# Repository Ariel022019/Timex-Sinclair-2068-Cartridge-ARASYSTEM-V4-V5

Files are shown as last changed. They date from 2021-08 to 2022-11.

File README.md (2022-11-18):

## :small_blue_diamond: Timex-Sinclair-2068-Cartridge-ARASYSTEM-V4-V5
This is a cartridge for Timex Sinclair 2068, to work with EPROMs 28C64, 27C128, 27C256, 27C512, EEPROMs 28C54, 28C256 and Static RAM 66256, 84256 and another with the same characteristics.  Using jumpers or mini switches, this PCB can be configured to get different settings.
With its unique design, there is no need to configure bridges to select fragments. The chunks can be configured by software.

### :small_blue_diamond: Jumpers configutation for each kind of EPROM /EEPROM

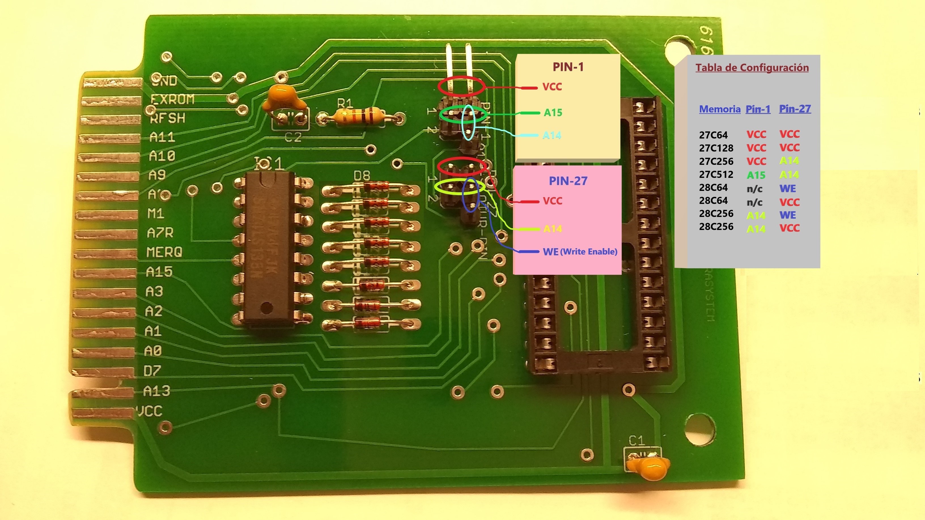
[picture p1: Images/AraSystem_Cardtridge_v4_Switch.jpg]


### :small_blue_diamond: Place right way to the socket the EPROM / EEPROM 

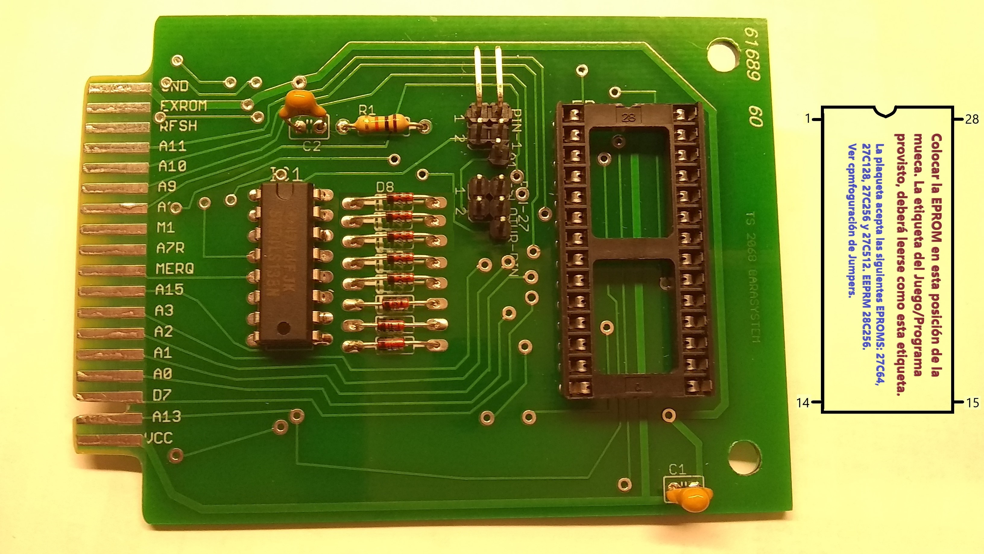
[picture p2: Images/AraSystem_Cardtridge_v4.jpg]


#### 🔸 Watch the creation of the first cartridge on video 
[Youtube Video Link](https://www.youtube.com/watch?v=S2ucEzxKyNs)

### 🔹 Cartridges With Mini Switches.
These mini switches allows to divide the EPROM memory into two or four parts, depending on the size of the EPROM (32k or 64K).

######  ▪️ ▪️ EPROM 27C256 divided into two 16K sizes


[See video example on Youtube](https://www.youtube.com/watch?v=SSa5LG2SbeI)

######  ▪️ ▪️ EPROM 27C512 divided into four 16K sizes


[See video example on Youtube](https://www.youtube.com/watch?v=w1bCyKRASG4)

######  ▪️ ▪️ Combining various configurations with switches and jumpers
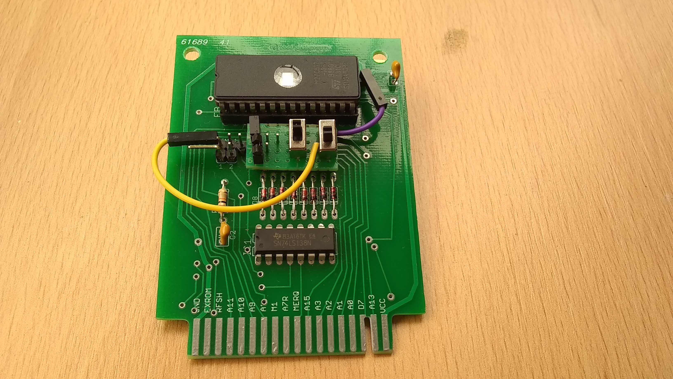
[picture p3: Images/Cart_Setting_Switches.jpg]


### 🔹 Timex Sinclair 2068 Cartridge With 32K Static RAM 
This cartridge is used to expand 32K of RAM and store your own programs or data, which are stored in memory through a 3 Volt battery. Both the cartridge board and the battery holder board have their protection diodes, so as not to interfere with the voltages between them.
Commercial programs that start in AROS mode can also be stored. (Only one game at a time, eg Flight Simulator, Androids, Crazy Bugs, Casino 1 and others).
this system is that they can generate / experiment cartridges, without the need for burners and / or ERPOM erasers.

######  ▪️ ▪️ Battery connection.


######  ▪️ ▪️ Static RAM located in the socket.


######  ▪️ ▪️ Inserted inside the Dock Bank.
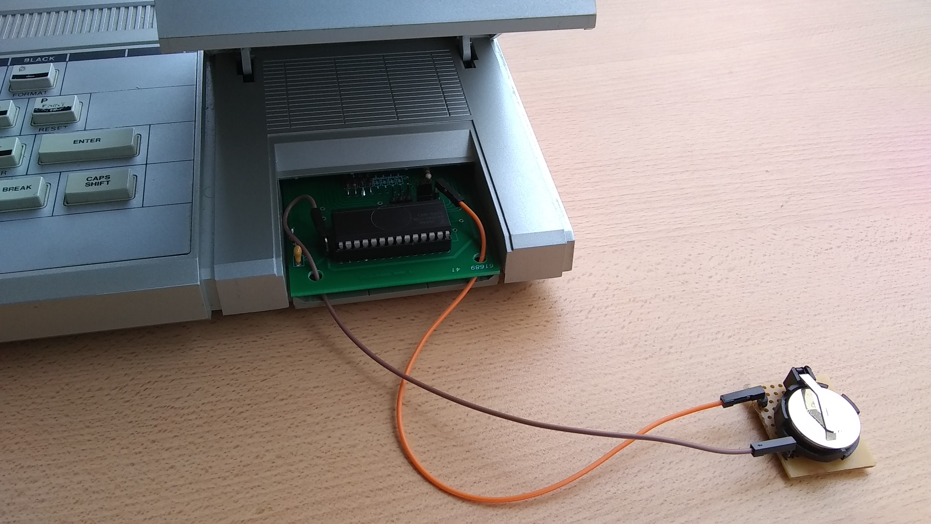
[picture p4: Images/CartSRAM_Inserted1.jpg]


[Demo on Youtube](https://www.youtube.com/watch?v=_XW6AfT9foQ)

## 🔸 License.

######  UNDER LICENSE: CC BY NC ND 4.0
- You may not use the material for commercial purposes.

<a rel="license" href="http://creativecommons.org/licenses/by-nc-nd/4.0/">Attribution-NonCommercial-NoDerivatives 4.0 International</a><br />

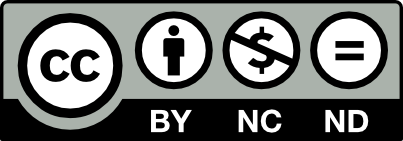
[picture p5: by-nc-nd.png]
Licencia de Creative Commons


#### 🔹 You can get these cartridges or more information:

Contact to: ariel.ranieri.sistemas@gmail.com

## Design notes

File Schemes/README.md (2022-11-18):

## 🔹 Design for every need.

This cartridge can be setting according to the needs of the end user

### 🔹 Cartridge scheme to replace jumpers using a switch and a jumper.

###### ◾ EPROM 27C256 divided into two equal parts 16K in size
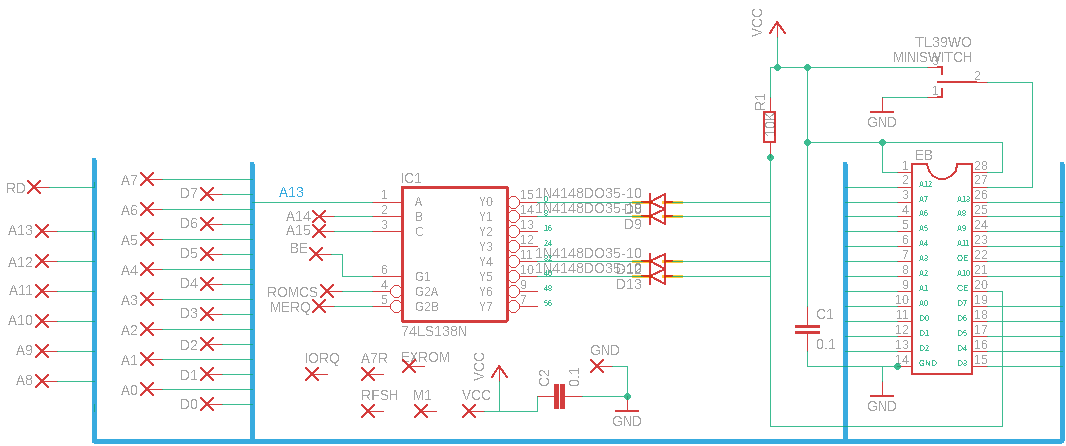
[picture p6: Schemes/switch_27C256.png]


###### ◾ EPROM 27C512 divided into two equal parts 32K in size
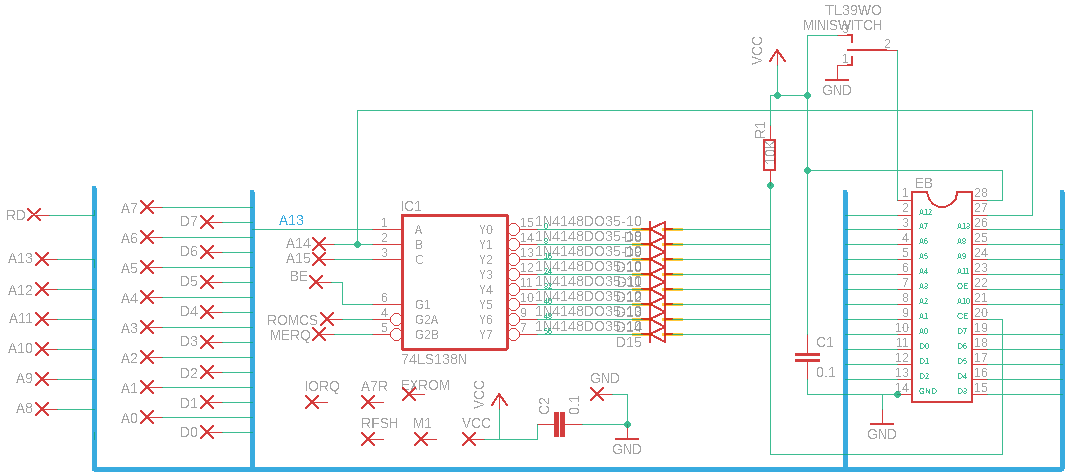
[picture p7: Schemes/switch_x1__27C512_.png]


### 🔹 Cartridge scheme to replace jumpers using two switch.

###### ◾ EPROM 27C512 divided into four equal parts 16K in size
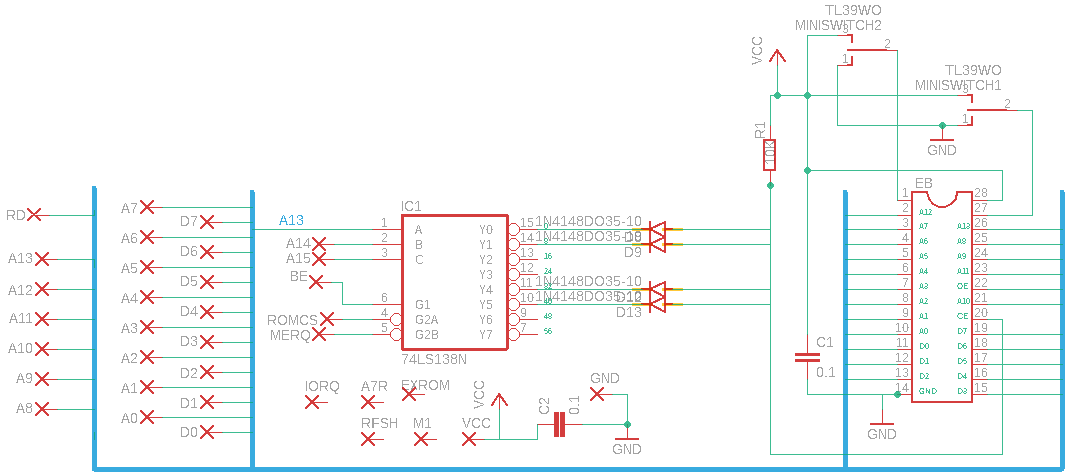
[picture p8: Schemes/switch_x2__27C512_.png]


### 🔸 Cartridge scheme to use static ram and battery.

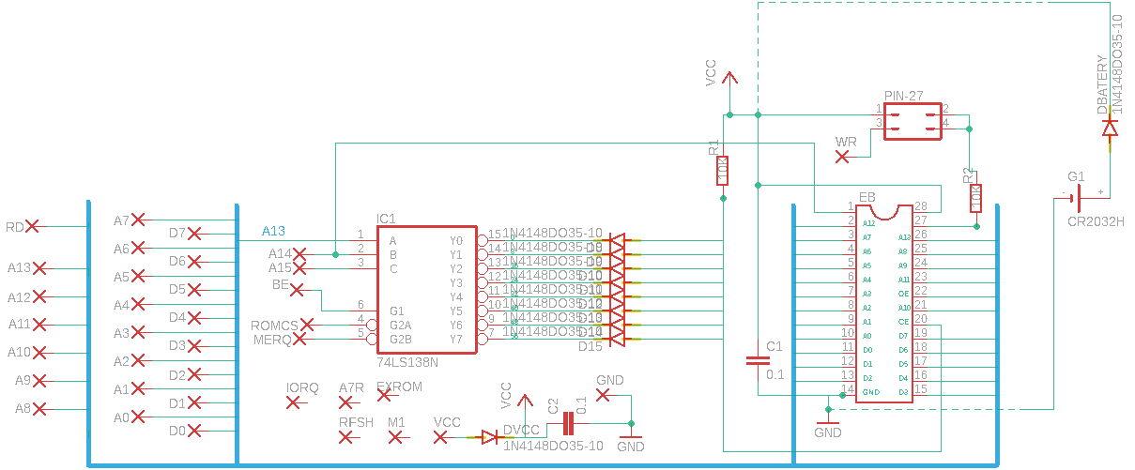
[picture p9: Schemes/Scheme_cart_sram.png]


### 🔸 Cartridge PCB Layer TOP.

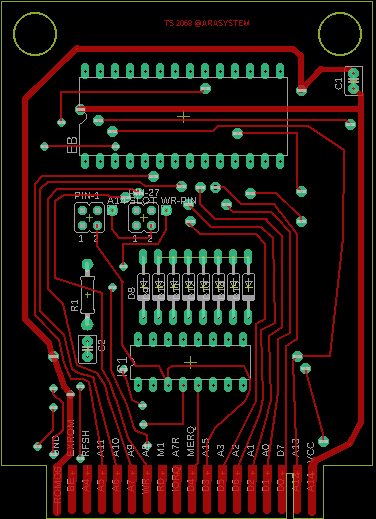
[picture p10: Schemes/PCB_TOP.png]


### 🔹 Cartridge PCB Layer Bottom.

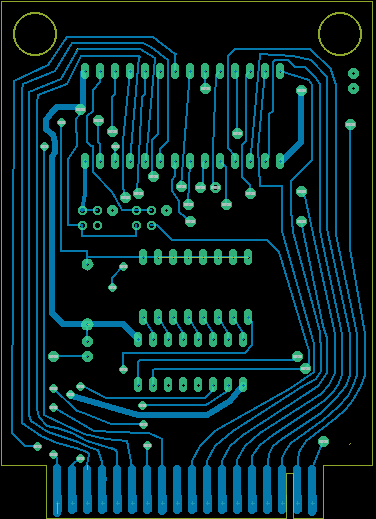
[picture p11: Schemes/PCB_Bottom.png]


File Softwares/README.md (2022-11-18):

## 🔹 Software Pack Built for Timex Sinclair 2068 Cartridges.

I have made several sets of programs for these cartridges. All files have the .Dck extension. That is means you can run this files on some Emulator like FUSE or others. Remember to skip or delete the first nine bytes when you want to write the binary file to some EPROM.
In this section I'll focus on the others games (most of the Spectrum games) and skip the seven classic games made for cartridges on the TS2068.

You will see that in all projects, I am using the emulator FUSE for get Snap Shot files, and then I am using the "SnapToTap R2.3 (PC/Windows), by Arda Erdikmen" for to convert from Snap Shot files to TAP format  from 
this URL: [World Of Spectrum Utilities](https://worldofspectrum.net/utilities/)

The binary file can be created to start or boot in LORS mode [Cartridge Loader Maker:](https://www.retrocomputacion.com/forum/hardware_s/108010/eproms-para-las-plaquetas-timex-sinclair-2068-command-cartridge-v2/&p=7), or in AROS mode  [Cartridge Maker AROS V2:](https://www.retrocomputacion.com/forum/hardware_s/108010/eproms-para-las-plaquetas-timex-sinclair-2068-command-cartridge-v2/&p=8)
Both web pages (they are in Spanish) explain how to do it.

### 🔹 Start in Mode LROS EEPROM 28C256 or EPROM 27C256.

The steps for make cartridges booting in LORS mode are:
1) From the FUSE Emulator in TS2068 mode, Load a program TZX or TAP file and then Create a Snap Shot file and save it on disk.
2) Convert Snap Shot file to .TAP .
3) Again From the FUSE program, load the "Cartridge Loader Maker" software and get the binary file.
4) Burn the binary file on the eprom.

### 🔹 Start in Mode AROS EEPROM 28C256 or EPROM 27C256.

The steps for make cartridges booting in AORS mode are:
1) From the FUSE Emulator in TS2068 mode, load a program TZX or TAP file and then Create a Snap Shot file and save it on disk.
2) Convert Snap Shot file to .TAP .
3) Again From the FUSE program, load the "Cartridge Maker AROS V2" software and get the binary file.
4) Burn the binary file on the eprom.

### 🔹 Start in Mode AROS With Menu from EPROM 27C512.
Make cartridges with two Games. The steps to do are:
Instructions for creating a Basic Menu To select two SnapShot programs. (Use the FUSE Emulator Program in TS2068 mode).

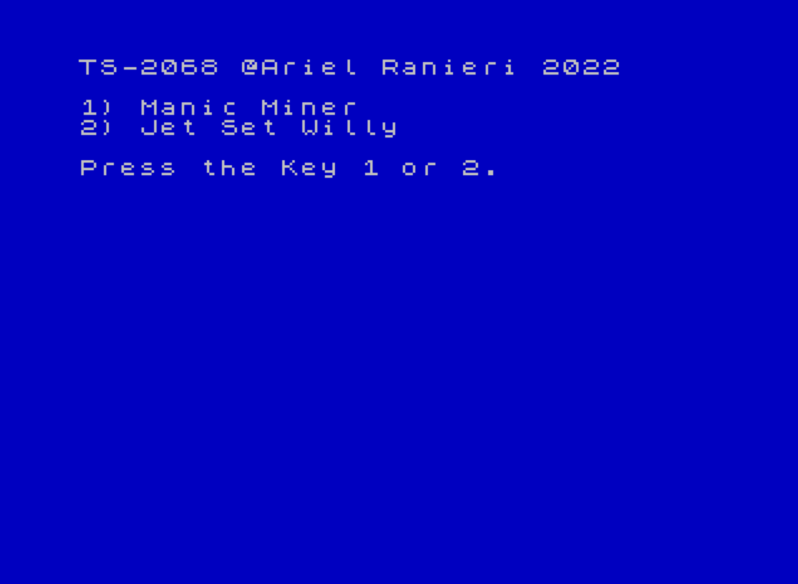
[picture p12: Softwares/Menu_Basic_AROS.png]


1) Create a snapshot for cartridge with LROS boot.
2) Create a Snap Shot for Cartridge with AROS boot.
3) Eraase the boot LROS mode(put 0 from the second byte to fourth byte in the file) and save it.
4) Change the boot AROS mode to AROS Basic (put 1 on the first byte in the file) and save it.
5) From the FUSE Emulator in TS2068 mode, load the Program Menu_Basic_AROS.tzx file, then edit line 5 and write the names of the programs. The first program "1)",    executes the snapshot prepared to boot type LROS. The second program "2)", executes the snapshot, ready to start type AROS.
6) Save from the FUSE in binary format with file name menu_basic_LORS_AROS.bin, as Start = 26710 , Length = 320.
7)  Load the binary file (created in the item 2) from memory address 32768 an then load the other binary file menu_snap_LROS_AROS.bin from the FUSE, with the Start    parameter = 32776, and Length the one indicated by the size of the binary file (320 bytes, it must not exceed this size as described above).
8) Load the binary file headerAros.bin from the FUSE, with the parameter Start = 33096, and Length the one indicated by the size of the binary file (168 , respect this size).
9) Save from the FUSE the program in binary format as Start = 32768 and length = 32768.
10) Concatenate with the DOS COPY command, the two binary files to burn them on 27C512 EPROM (Using for example the Xgpro TL866II PLUS program). 
    copy /b CARTRIDGE_SMAP_LROS.bin+CARTRIDGE_SMAP_AROS.bin MI_CARTRIDGE_FINAL.bin .
11) If you want to test it in the Fuse emulator, we add the 9 Bytes header (0-2-2- 2-2-2-2-2-2)
    copy /b Header_DOCK.bin+MI_CARTRIDGE_FINAL.bin Cartridge.dck 
    
#### 🔸 Videos Youtube
[Cartridge: Manic Minier and Jet Set Willy](https://www.youtube.com/watch?v=gIqrhjyPwj8)

[Cartridge: ROM ZX Spectrum and Poe Position](https://www.youtube.com/watch?v=1JByrzgxnWw)

### 🔹 Built to lung and using too much the wrist.
This is the hardest way to build cartridges that boot the programs from any Dock Bank memory address.
The 7Games9K.DCK (7 Games 9K bytes) and 8Games8K.DCK (8 Games 8K bytes) files are more complicated to build. It is necessary to make an installer for each of the games and place them in the best place in the eprom (27C512). And play with the eight 8Kbyte chunks, the Stack Point and other environments.

#### 🔸 Videos Youtube
[Cartridge: 7 Games of 9Kbytes](https://www.youtube.com/watch?v=phbGwPkzN14)

[Cartridge 8 Games of 8Kbytes](https://www.youtube.com/watch?v=hWecyYZo_lU)

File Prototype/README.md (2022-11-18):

## 🔹  Cartridge-Prototype-ARASYSTEM-V4
Theses were the first steps for build the unique cartridge prototye. 

### :small_blue_diamond: PCB - Scheme

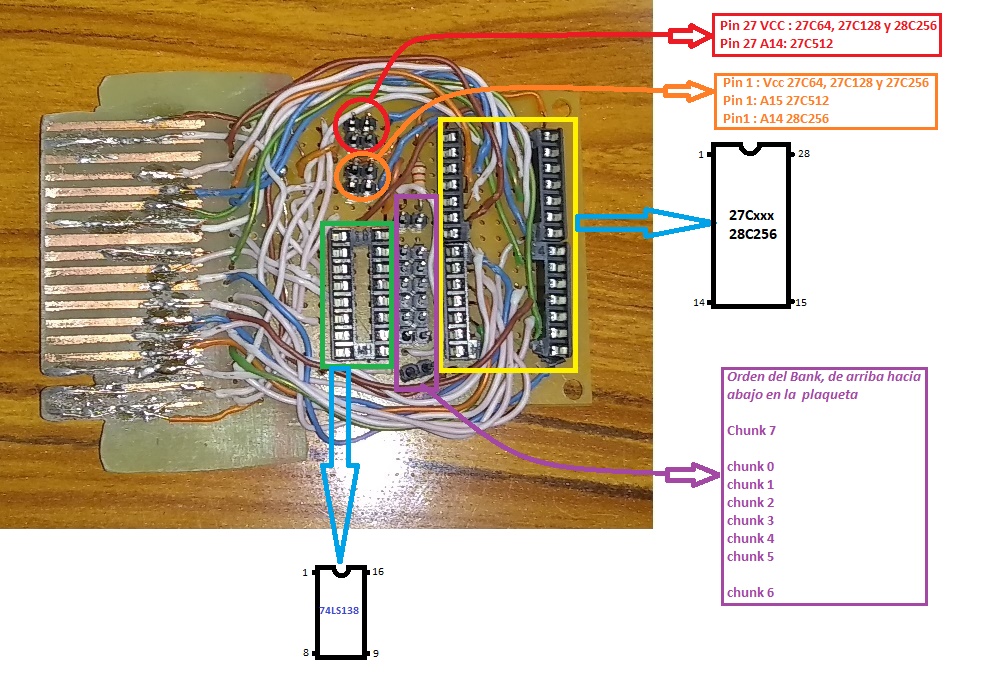
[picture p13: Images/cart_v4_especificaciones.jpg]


### :small_blue_diamond: PCB Prototype on Dock Bank Slot

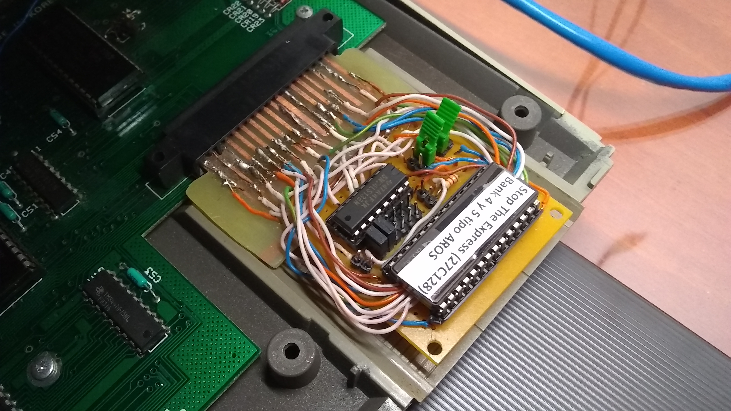
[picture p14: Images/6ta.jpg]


### 🔹 Final design, adding an external protobard.

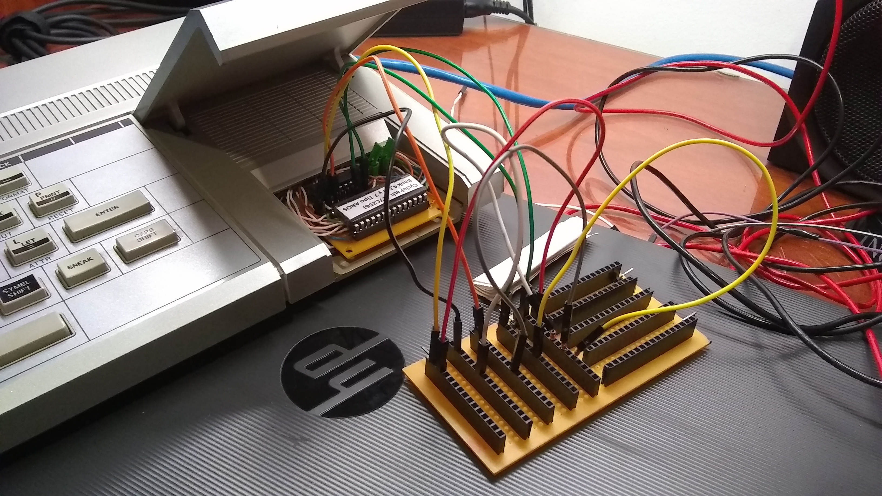
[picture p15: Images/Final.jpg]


### 🔹 PCB Ready!.

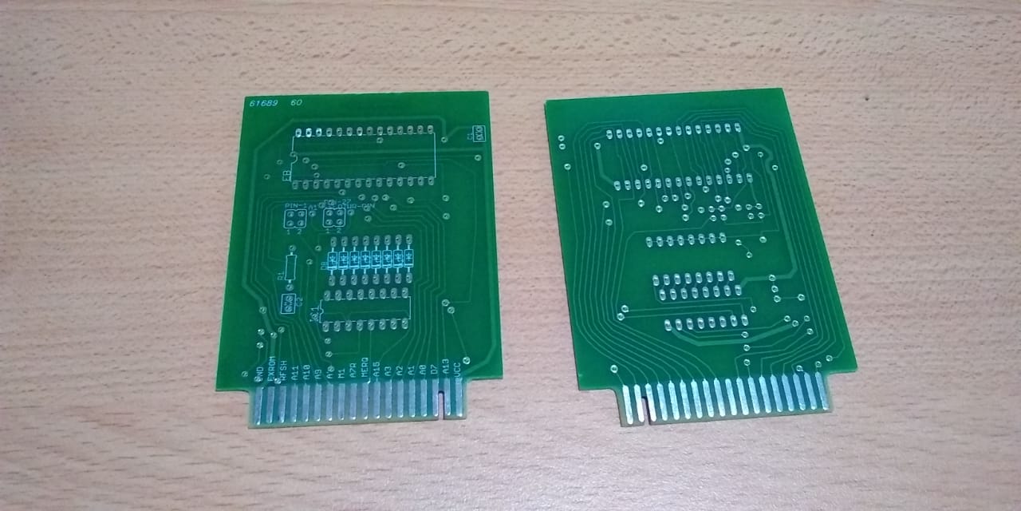
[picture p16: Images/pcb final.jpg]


### 🔹 New PCB with components and located on Dock Bank.

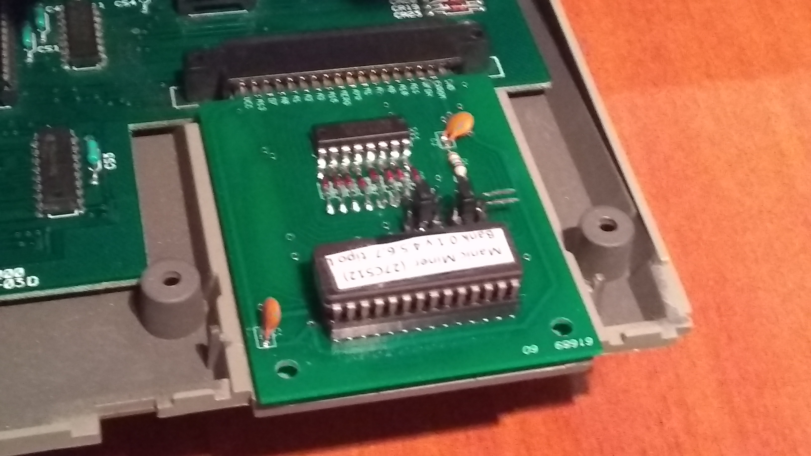
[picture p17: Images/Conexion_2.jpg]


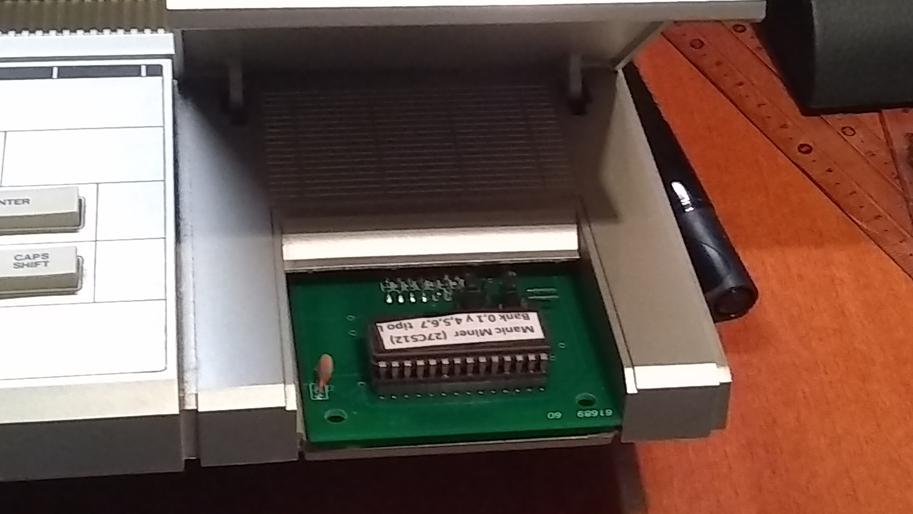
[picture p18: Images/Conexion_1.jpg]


### 🔹 The Laboratory.

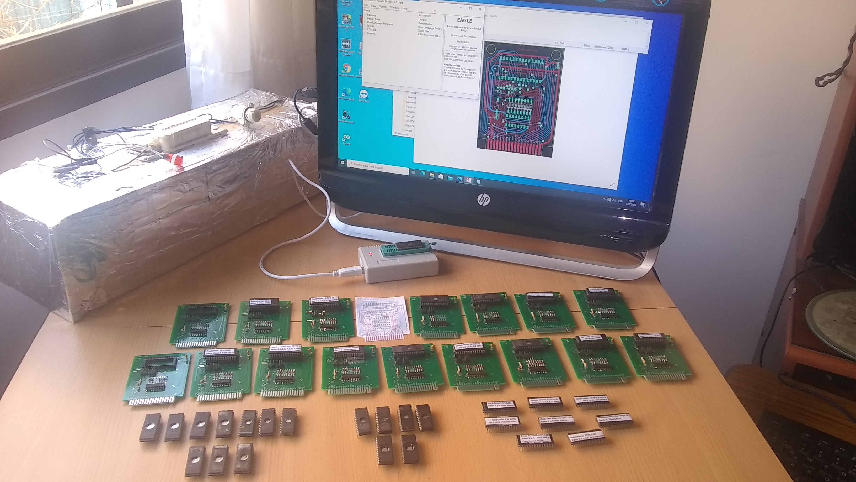
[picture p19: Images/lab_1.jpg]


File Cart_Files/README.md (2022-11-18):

## 🔹 How to use the WriteCart program in TS2068 to create your own cartridges.

[Link How To on Youtube](https://www.youtube.com/watch?v=_XW6AfT9foQ)

### 🔸 Step 1. Load the file WriteCart.tzx in TS2068.

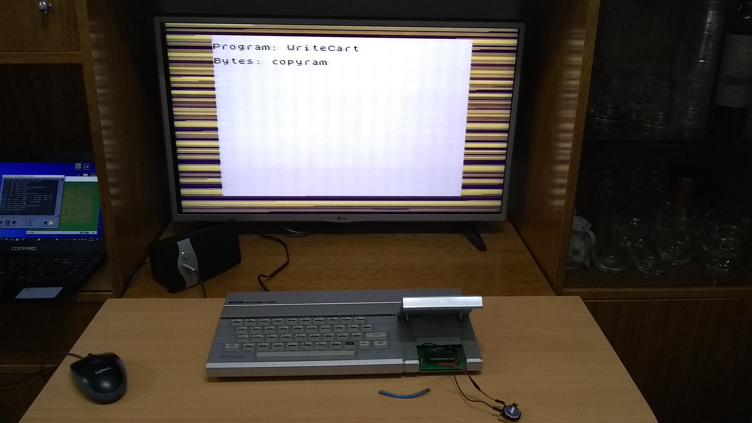
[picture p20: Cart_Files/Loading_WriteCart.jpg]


### 🔸 Step 2. Choice the option 1)

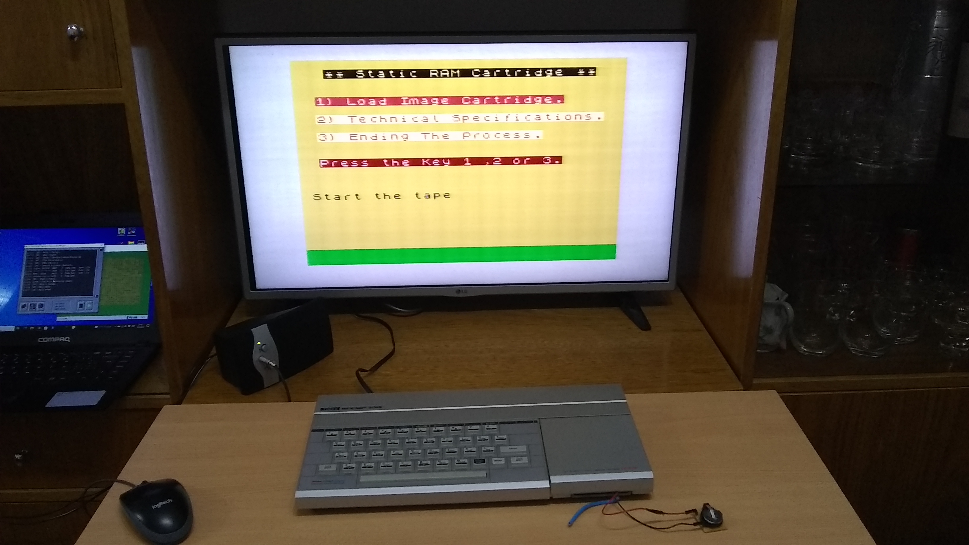
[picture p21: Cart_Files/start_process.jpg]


If the cartridge has the jumper in write-protect mode, change the jumper to the correct position.

### 🔸 Step 3. Load the file image TZX selected from the list. All these games are booting in AROS mode.

###### ◾ Choice some TZX files to load ,from Pack_Cart_SRAM.rar

### 🔸 Step 4. After to load the Game, the program will show this screen.

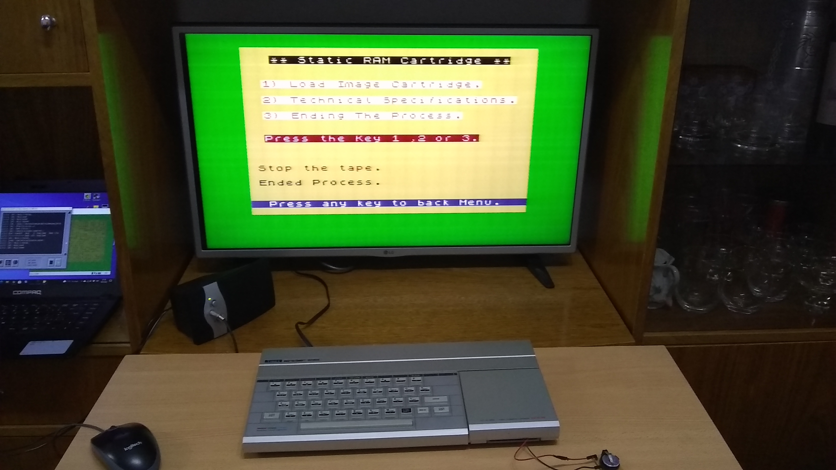
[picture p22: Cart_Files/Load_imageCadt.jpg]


### 🔸 Step 5. Select option 3) and read and follow the instructions.

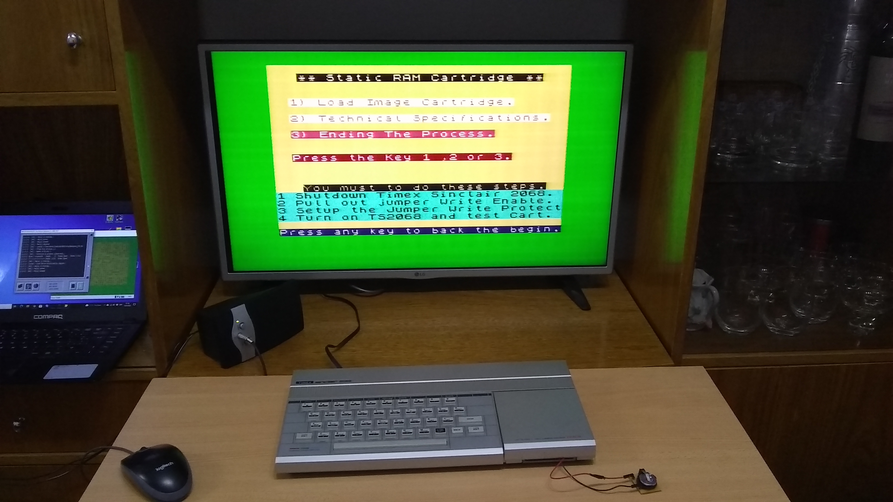
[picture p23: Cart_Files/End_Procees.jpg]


#### 🔺 WARNING: Always insert and eject the cartridge while the TS2068 is turn off.

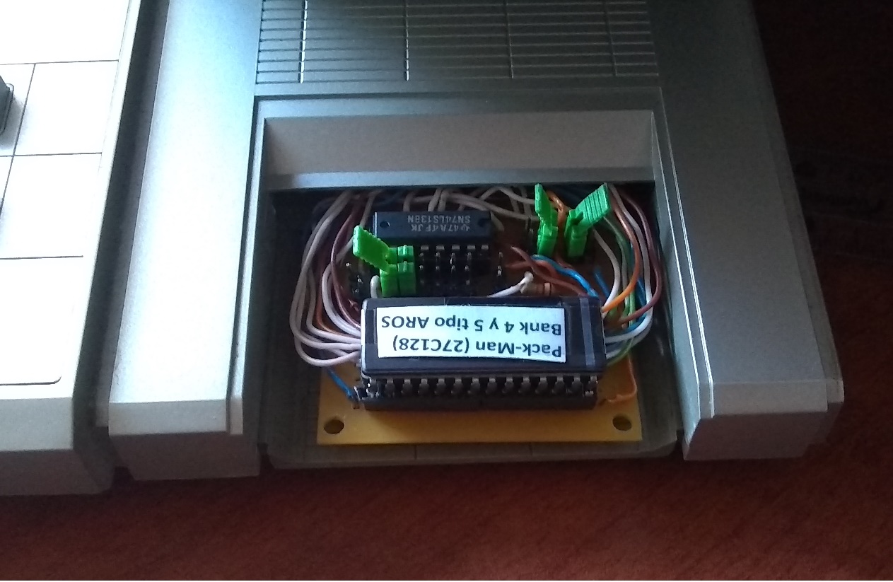
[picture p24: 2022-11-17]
Images/4tacv4.jpg

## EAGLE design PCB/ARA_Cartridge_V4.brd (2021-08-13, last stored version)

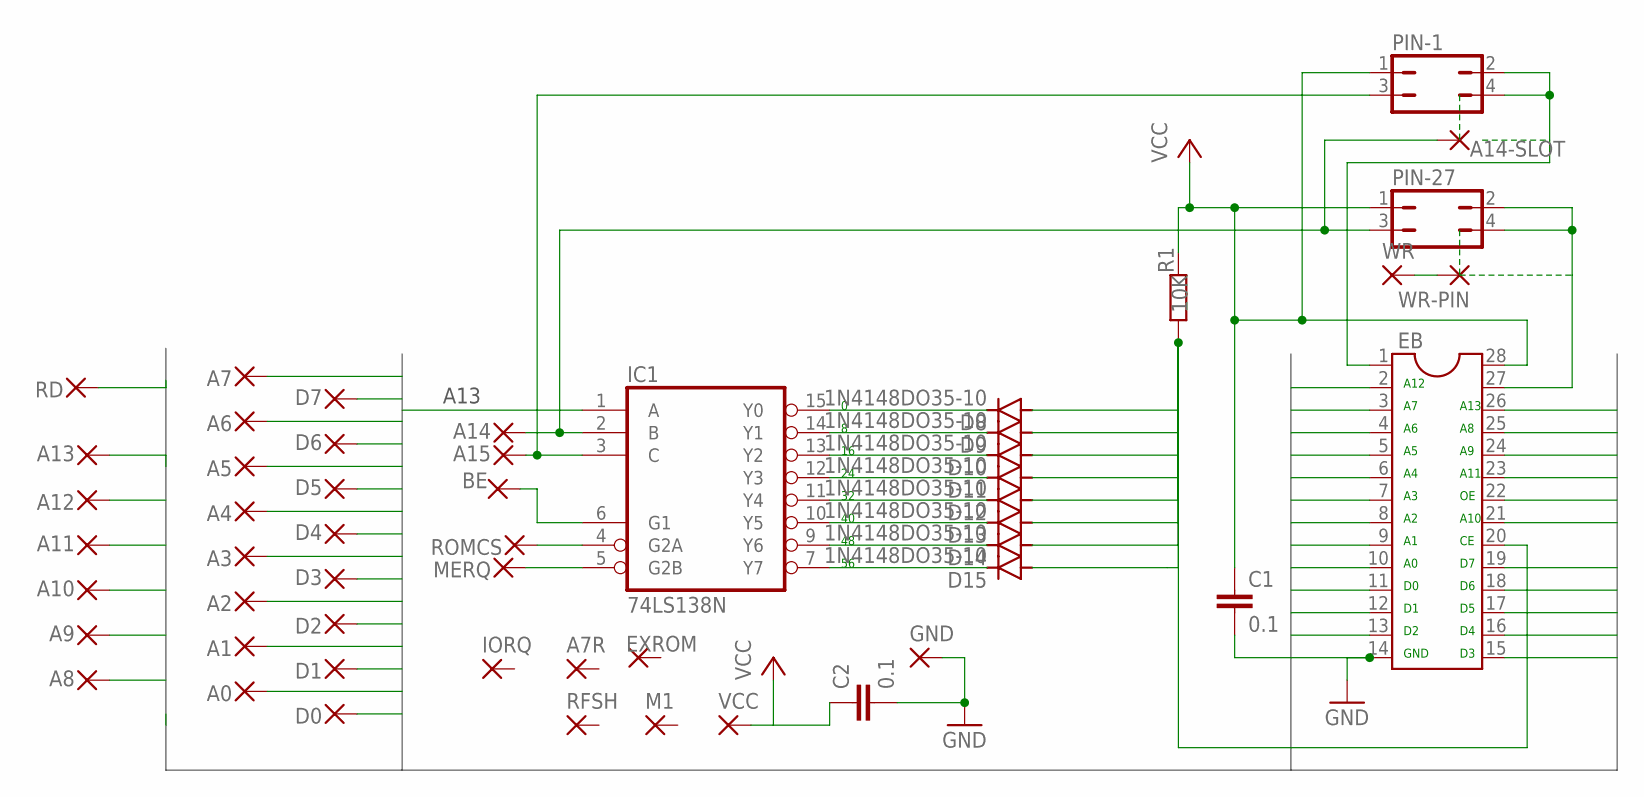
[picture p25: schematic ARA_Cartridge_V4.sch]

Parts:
A0, A1, A2, A3, A4, A5, A6, A7, A7R, A8, A9, A10, A11, A12, A13, A14, A15: SMD2
A14-SLOT: 1,6/0,8
BE: SMD2
C1, C2: 0.1; C2.5-3
D0, D1, D2, D3, D4, D5, D6, D7: SMD2
D8, D9, D10, D11, D12, D13, D14, D15: 1N4148DO35-10; DO35-10
EB: DIL28; DIL28-6
EXROM: SMD2
GND: SMD2
IC1: 74LS138N; DIL16
IORQ: SMD2
M1: SMD2
MERQ: SMD2
PIN-1, PIN-27: JP2Q
R1: 10K; 0207/10
RD: SMD2
RFSH: SMD2
ROMCS: SMD2
VCC: SMD2
WR: SMD2
WR-PIN: 1,6/0,8

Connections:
A0: A0.1, EB.10
A1: A1.1, EB.9
A2: A2.1, EB.8
A3: A3.1, EB.7
A4: A4.1, EB.6
A5: A5.1, EB.5
A6: A6.1, EB.4
A7: A7.1, EB.3
A8: A8.1, EB.25
A9: A9.1, EB.24
A10: A10.1, EB.21
A11: A11.1, EB.23
A12: A12.1, EB.2
A13: A13.1, EB.26, IC1.1 (A)
A14-EP: EB.27, PIN-27.2, PIN-27.4
A14-I: A14.1, A14-SLOT.1, IC1.2 (B), PIN-27.3
A15-EP: EB.1, PIN-1.2, PIN-1.4
A15-I: A15.1, IC1.3 (C), PIN-1.3
B0: D8.C, IC1.15 (Y0)
B1: D9.C, IC1.14 (Y1)
B2: D10.C, IC1.13 (Y2)
B3: D11.C, IC1.12 (Y3)
B4: D12.C, IC1.11 (Y4)
B5: D13.C, IC1.10 (Y5)
B6: D14.C, IC1.9 (Y6)
B7: D15.C, IC1.7 (Y7)
BE: BE.1, IC1.6 (G1)
D0: D0.1, EB.11
D1: D1.1, EB.12
D2: D2.1, EB.13
D3: D3.1, EB.15
D4: D4.1, EB.16
D5: D5.1, EB.17
D6: D6.1, EB.18
D7: D7.1, EB.19
GND: C1.2, C2.2, EB.14, GND.1, IC1.8 (GND)
unnamed: D8.A, D9.A, D10.A, D11.A, D12.A, D13.A, D14.A, D15.A, EB.20, R1.2
unnamed: IC1.5 (G2B), MERQ.1
unnamed: IC1.4 (G2A), ROMCS.1
RD: EB.22, RD.1
VCC: C1.1, C2.1, EB.28, IC1.16 (VCC), PIN-1.1, PIN-27.1, R1.1, VCC.1
WR: WR.1, WR-PIN.1

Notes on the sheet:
A13
A12
GND
A10
A11

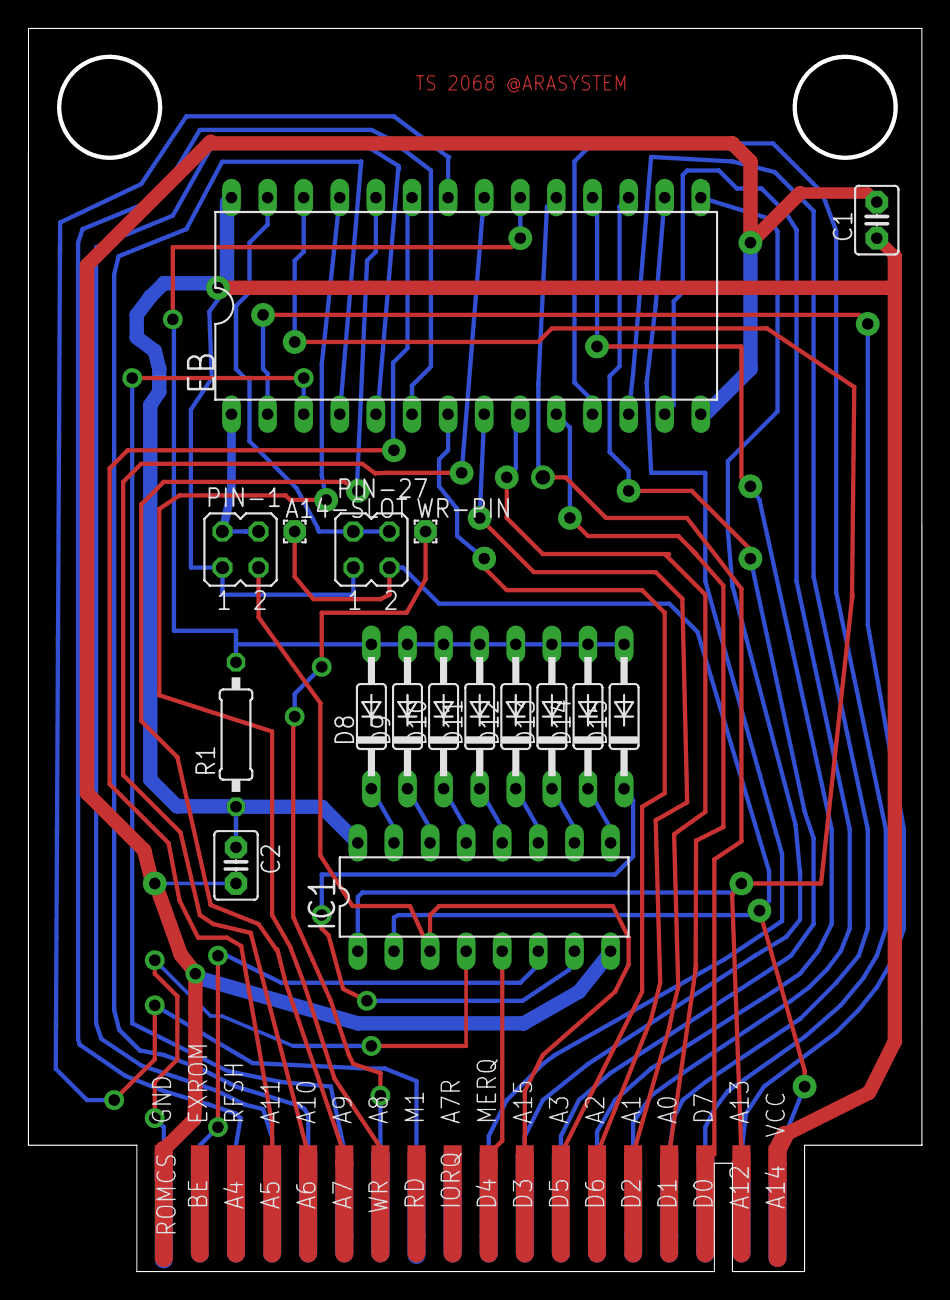
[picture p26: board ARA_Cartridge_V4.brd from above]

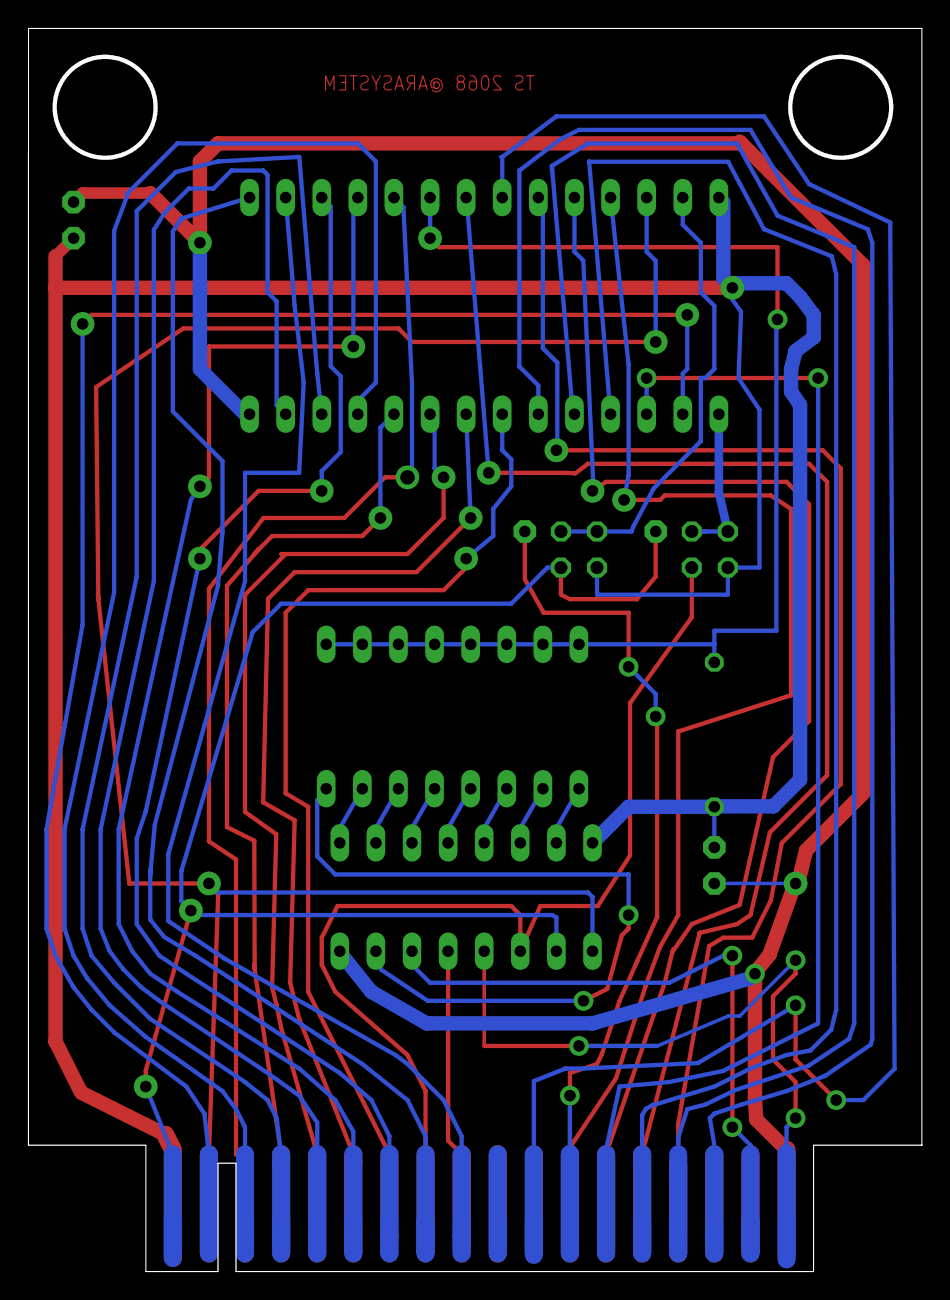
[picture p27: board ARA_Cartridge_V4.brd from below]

Board: 2 copper layers, 62.9 x 87.5 mm, 53 parts (18 on the bottom side), 42 nets.

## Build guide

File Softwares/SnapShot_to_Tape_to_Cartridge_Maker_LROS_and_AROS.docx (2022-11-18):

Método SnapShot. Hasta ahora para poder hacer compatible la carga de Juegos/Programas de la ZX Spectrum en la Timex Sinclair 2068, consistía en generar en assembler un nuevo load "" code y RANDOMIZE USR xxxxx , para programas que cargaran detrás de la zona de basic de la 2068, o programas de cintas sin cabeceras que utilizan llamadas a rutinas de la ROM de la Spectrum, ubicada en direcciones de memorias incompatible con la TS2068. Otro dato a tener en cuenta, es la ubicación del registro assembler SP (Stack Point), donde direcciona en la memoria la pila de máquina. Y algunos detalles mas, que a veces son necesarios de trabajar , por ejemplo: cuando el inicio de la carga del juego está protegido con ANTI-MERGE, ANTI-BREAK, código máquina después de una sentencia REM, etc.

Muchas de estas rutinas en assembler, se podía generar automáticamente con el programa Header-Maker , con los datos de la zona de carga en memoria, que se podían obtener con el programa Analizador de Tapes (ambos programas publicados en este foro). Y para los casos mas ceberos el uso de un dessessamblador.

Sin dejar dejarlo de lado y olvidado este método a pulmón, voy a dejar un par de herramientas interesantes para trabajar con archivos snapshot, el cual nos va a permitir de una forma mas práctica, compatibilizar programas de la ZX Spectrum con la Timex Sinclair 2068.

SnapToTap: Este es un programa para Windows que carga un archivo snapshot o Z80 y lo convierte en un archivo tipo TAP con la estructura de nombre : nnnnn_xxxxx.tap .

Donde nnnnn , es el nombre del archivo snap o Z80 y xxxxx, es un número de cinco dígitos, donde comienza a cargar el programa assembler en memoria. Siempre con nombre "v2".

Los ejemplos que voy a dar, es utilizando el programa emulador FUSE.

a) Cargar un programa de Spectrum en el Fuse (emulando Spectrum 48K), y desde el menú principal del juego/programa, generar un archivo snapshot en el menú de FUSE: File-->Save snapshot..

b) Desde el programa de Windows snaptoTap, abrir el archivo .sna , esperar que procese y luego salvarlo en el disco. (con su clásico nombre nnnnn_xxxxx.tap).

c) Probar de cargar el archivo TAP en el emulador FUSE en modo ZX 48K, y si el juego o programa cargar y corre perfectamente, probarlo en una TS2068 o en el mismo FUSE en modo 2068.

Si un programa de la Spectrum utiliza rutinas de la ROM, es probable que se cuelgue o resete al instante. (que es lo mismo me pasaba con el método tradicional).

Una característica de estos programas capturados por un snapshot y convertidos a TAP, es que el cargardor snapshot , se instala en los primeros 1000 bytes de la zona de memoria de la pantalla (16384) para acomodar correctamente el programa y todos los registros del assembler. Por lo que se observará un poco "sucia" las primeras cuatro o cinco filas de la pantalla. Luego se acomoda cuando se cambia de pantalla o se vuelve a la principal.

Hay juegos, que tiene pantalla fija en la parte superior y conviven con algunso puntitos, como ser el juego 3D Tank Duel.

Cartridge Loader Maker: Con este programa en Basic que se debe ejecutar desde emulador FUSE en modo TS2068 , genera en código assembler, el encabezado de arranque del cartridge en la 2068 y ejecución del programa snapshot.

Siguiendo el método snapshot del otro POST :LINK , se pueden crear archivo binarios para cartridge. una vez generado el archivo TAP (nnnnn_xxxxx.tap).

Pasos a seguir:

1) Cargar el bloruqe "v2" assembler del archivo nnnnn_xxxxx.tap

2) Ingresar los cínco dígitos xxxxx

3) Confirmar si los datos son correctos.

3) Grabar el archivo binario para el emulador .dck o otro archivo para una eprom del tipo 27C256 (Modo LROS trabajando en los sectores 0,1,2 y 3 del Dock Bank).

4) Volver a generar otro archivo binario o salir del programa.

Tips a tener en cuenta. El archivo .sna snapshot final, deberá estar generado con el emulador FUSE en modo TS2068. Hay casos que no arranque o funcione bien el cartrdige, por lo cual es recomendable realizar un nuevo snapshot en otra pantalla, o siguiente secuencia. Esto es debido a que el registro assembler SP, está posicionado en una dirección de memoria no compatible con el arranque del cartridge.

Cartridge Maker AROS V2: Es una versión nueva derivado del programa Cartridge Loader Maker , para generar archivos de cartridge en formato AROS para los cartridges que solo pueden configurarse los 32k superior del DOCK BANK. Recordemos que la versión anterior genera los archivos bin del cartridge para arrancarlos en modo LROS.

La pantalla es similar y más fácil de operar, el archivo TAP, previamente generado del programa snapTAP (Explicado anteriormente).

Este programa (Cartridge Maker AROS V2 ) también debe ejecutarse en el emulador FUSE, al igual que el anterior (Cartridge Loader Maker).

Documento: YPF-Público
